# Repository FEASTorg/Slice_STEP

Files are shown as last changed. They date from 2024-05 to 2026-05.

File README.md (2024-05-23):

<div align="center">
  <!-- Title: -->
  <a href="https://github.com/uwo-fast">
    
  </a>
  <h2><a href="https://github.com/uwo-fast/Slice_STEP"> STEP Slice </a></h2>
  <!-- Labels: -->
  <!-- First row: -->
  <a href="https://github.com/uwo-fast/.github/blob/main/collaborating.md">
    
  </a>
  <a href="https://github.com/uwo-fast/.github/blob/main/contributing.md">
    
  </a>
  <a href="https://www.appropedia.org/Category:FAST_literature_reviews">
    
  </a>
  <a href="https://certification.oshwa.org/">
    
    <!-- img src="https://img.shields.io/badge/OSHWA-Certified-darkgreen?style=flat-square" height="20" alt="OSHWA" -->       <!-- img src="https://img.shields.io/badge/OSHWA-Pending-darkorange?style=flat-square" height="20" alt="OSHWA" -->
  </a>
  <a href="https://osf.io/">
    
  </a>
  <a href="https://doi.org">
    
  </a>
  <!-- Second row: -->
  <br>
  <a href="https://github.com/uwo-fast/Slice_STEP/blob/main/LICENSE">
    
  </a>
  <a href="https://github.com/uwo-fast/Slice_STEP">
    
  </a>
  <a href="https://github.com/uwo-fast/Slice_STEP/issues">
    
  </a>
  <a href="https://github.com/uwo-fast/Slice_STEP/network/members">
    
  </a>
  <a href="https://github.com/uwo-fast/Slice_STEP/stargazers">
    
  </a>
  <!-- Short description: -->
  <h3>Stepper Motor Driver Carrier Slice for BREAD.</h3>
</div>

## Introduction
[Provide a brief introduction to the project, including the motivation and goals. Explain the significance and context of the research.]

## Project Overview
[Describe the project in more detail. This section can be split into subsections if necessary.]

## Installation
[Provide instructions for installing any necessary software or hardware components.]

## Usage
[Explain how to use the project. Include examples and screenshots if applicable.]

### Basic Usage
[Provide basic usage instructions.]

### Advanced Usage
[Provide advanced usage instructions, including any optional features or configurations.]

## Documentation
[Link to the detailed documentation if available. Provide instructions on how to access and navigate the documentation.]

## Contributing
[Explain how others can contribute to the project. Include guidelines for submitting issues, pull requests, and any coding standards.]

### Code of Conduct
[Link to the project's code of conduct if available.]

## License
[State the license under which the project is distributed. Include a link to the full license text.]

## Acknowledgements
[Acknowledge any contributors, collaborators, funding sources, or organizations that supported the project.]

## Contact
[Provide contact information for the project maintainer(s) or lead researcher(s). Include an email address or a link to a contact form.]

---

<div align="center">
  <p>
    
    
  </p>
</div>

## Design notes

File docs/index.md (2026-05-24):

---
title: "Slice STEP Documentation"
description: "Overview and entry page for Slice STEP project documentation."
nav_exclude: true
---

Welcome to the Slice STEP project documentation.

## Board Renders

<figure style="display:inline-block; text-align:center; margin:10px;">
  Board Top
  <figcaption>Top</figcaption>
</figure>

<figure style="display:inline-block; text-align:center; margin:10px;">
  Board Bottom
  <figcaption>Bottom</figcaption>
</figure>

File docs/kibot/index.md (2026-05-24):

---
title: "KiBot Outputs"
description: "Index for KiBot-generated PCB artifacts."
layout: "page"
---

These are the docs & KiBot Outputs for Slice STEP

The following files were generated from the latest PCB build:

- [Schematic.pdf](./Schematic.pdf)
- [PCB.pdf](./PCB.pdf)
- [kibot.log](./kibot.log)
- [BREAD_Slice-bom.html](./BREAD_Slice-bom.html)
- [BREAD_Slice-ibom.html](./BREAD_Slice-ibom.html)

_Last updated automatically by KiBot via GitHub Actions._

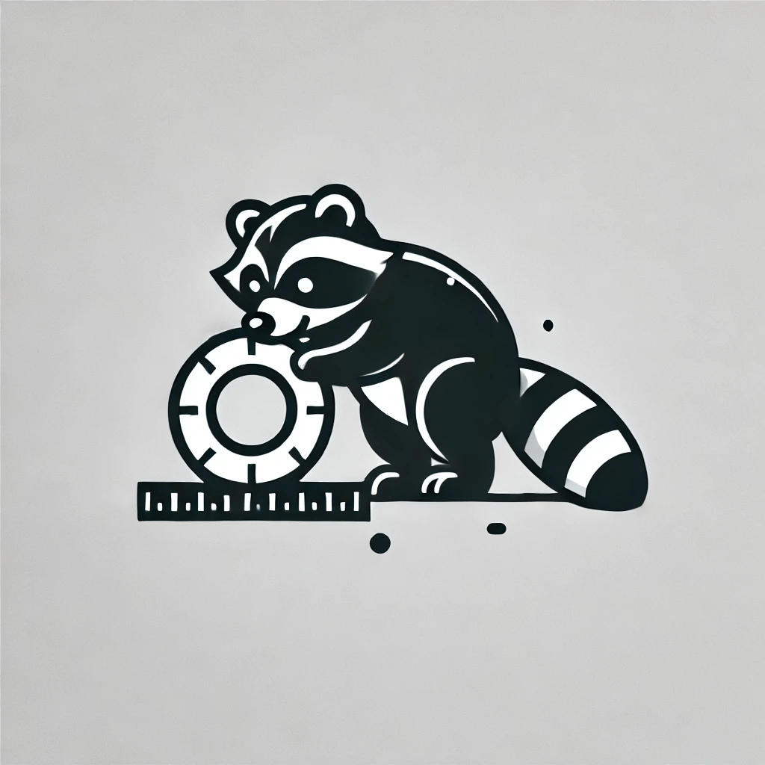
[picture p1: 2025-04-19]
hardware/stepping-raccoon.png

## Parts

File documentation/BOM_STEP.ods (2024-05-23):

Id | Designator | Package | Quantity | Designation | Supplier and ref
1 | J5 | PinSocket_1x03_P2.54mm_Vertical | 1 | Conn_01x03_Male | https://www.digikey.ca/en/products/detail/sullins-connector-solutions/PREC003SAAN-RC/2774851
2 | C3,C1,C2 | C_2312 | 3 | 10uF_t | https://www.digikey.ca/short/qfrbqfhd
3 | J6 | TerminalBlock_TE_282834-2_1x02_P2.54mm_Horizontal | 1 | Screw_Terminal_01x02 | https://www.digikey.ca/en/products/detail/on-shore-technology-inc/OSTVN02A150/1588862
4 | R4,R3,R2,R1 | R_1206_3216Metric_Pad1.30x1.75mm_HandSolder | 4 | 1k | https://www.digikey.ca/en/products/detail/stackpole-electronics-inc/RMCF1206FT1K00/1759616
5 | J4,J3 | TerminalBlock_TE_282834-8_1x08_P2.54mm_Horizontal | 2 | Screw_Terminal_01x08 | https://www.digikey.ca/en/products/detail/on-shore-technology-inc/OSTVN08A150/1588868
6 | J2 | TerminalBlock_TE_282834-4_1x04_P2.54mm_Horizontal | 1 | Screw_Terminal_01x04 | https://www.digikey.ca/short/tv7tzq1r
7 | A4,A3,A2,A1 | Pololu_Breakout-16_15.2x20.3mm | 4 | Pololu_Breakout_A4988 | https://www.pololu.com/product/1182
8 | G1 | Arduino_Nano | 1 | Arduino_Nano_v3.x | https://www.digikey.ca/en/products/detail/arduino/A000005/2638989
9 | J1 | PinSocket_1x10_P2.54mm_Horizontal | 1 | Conn_01x10_Female | https://www.digikey.ca/en/products/detail/sullins-connector-solutions/PPPC101LGBN-RC/775943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

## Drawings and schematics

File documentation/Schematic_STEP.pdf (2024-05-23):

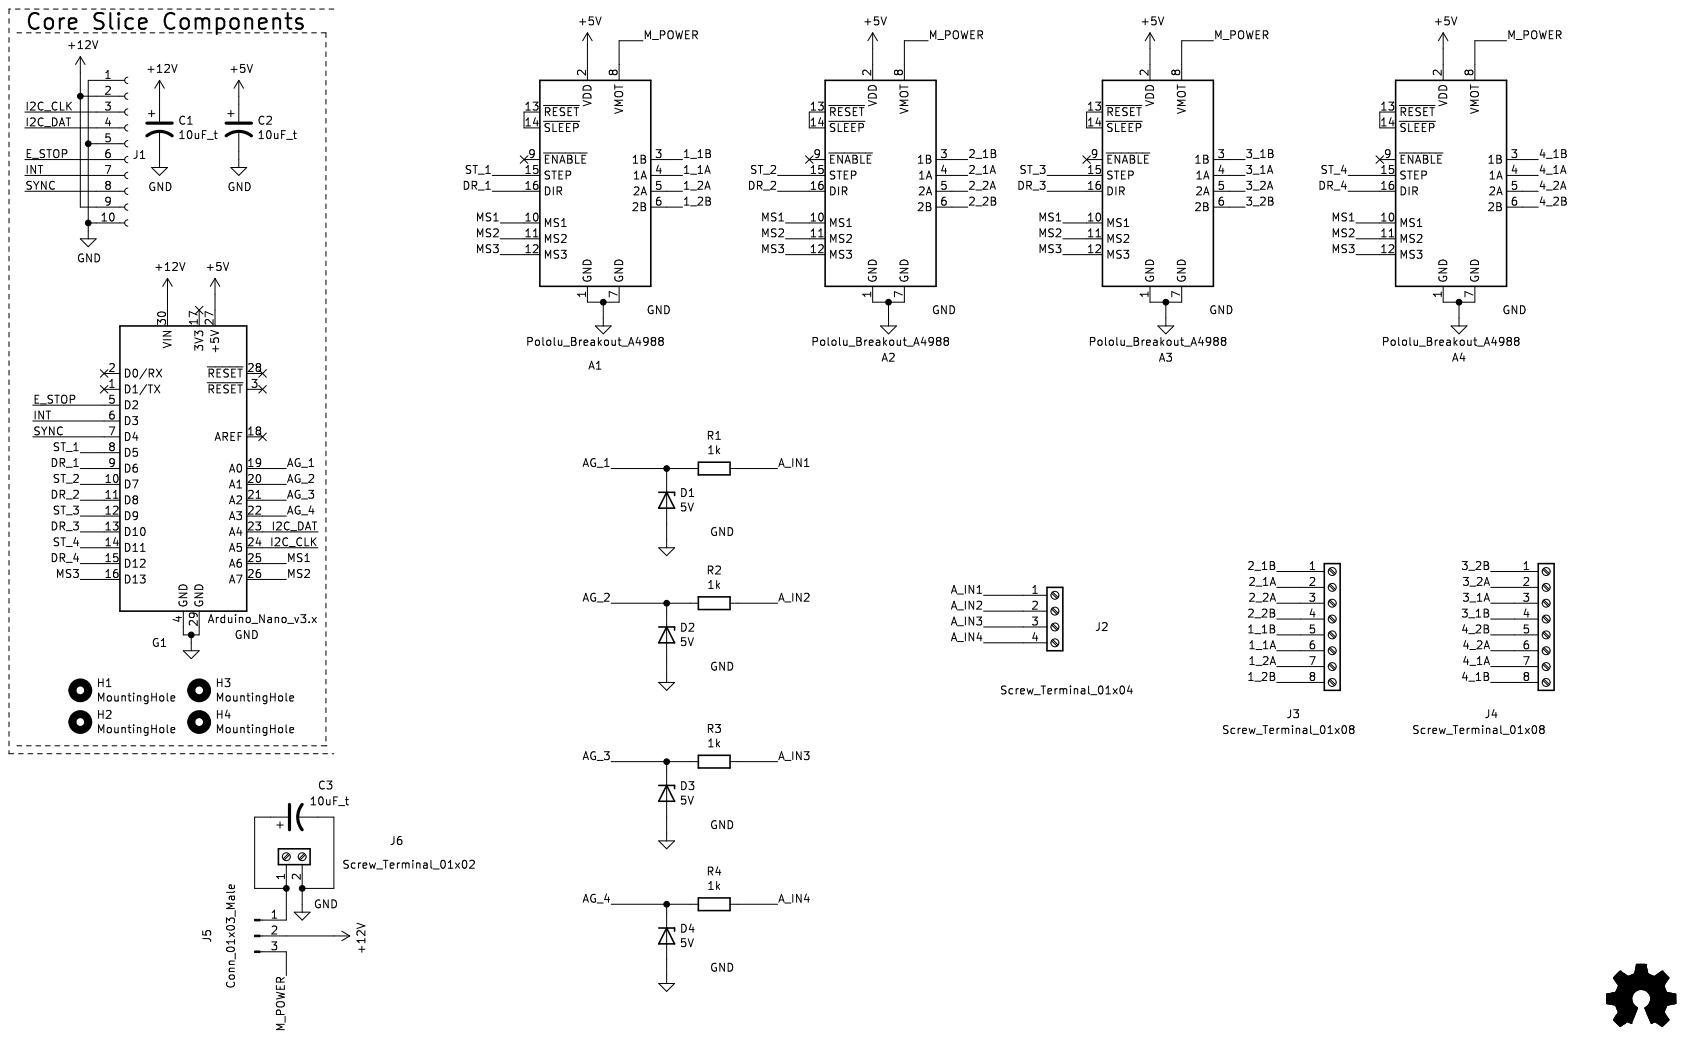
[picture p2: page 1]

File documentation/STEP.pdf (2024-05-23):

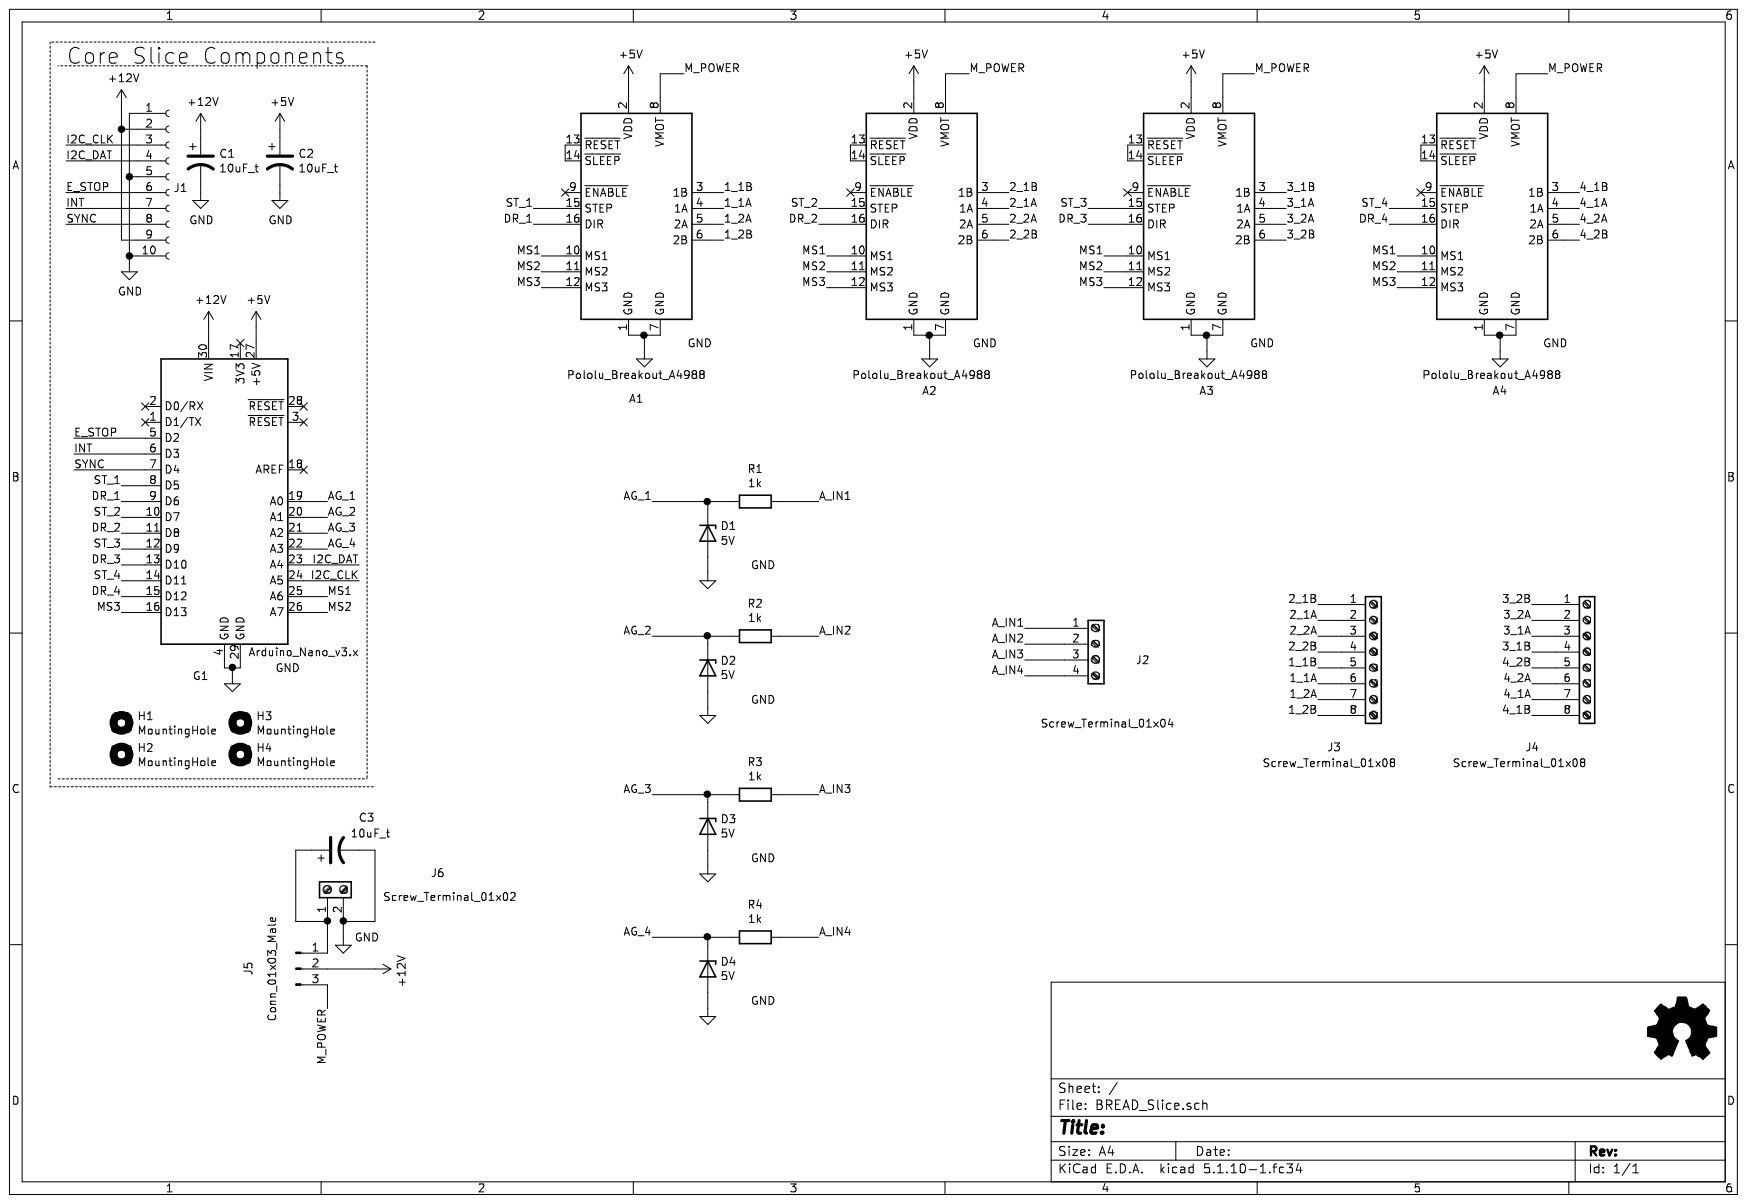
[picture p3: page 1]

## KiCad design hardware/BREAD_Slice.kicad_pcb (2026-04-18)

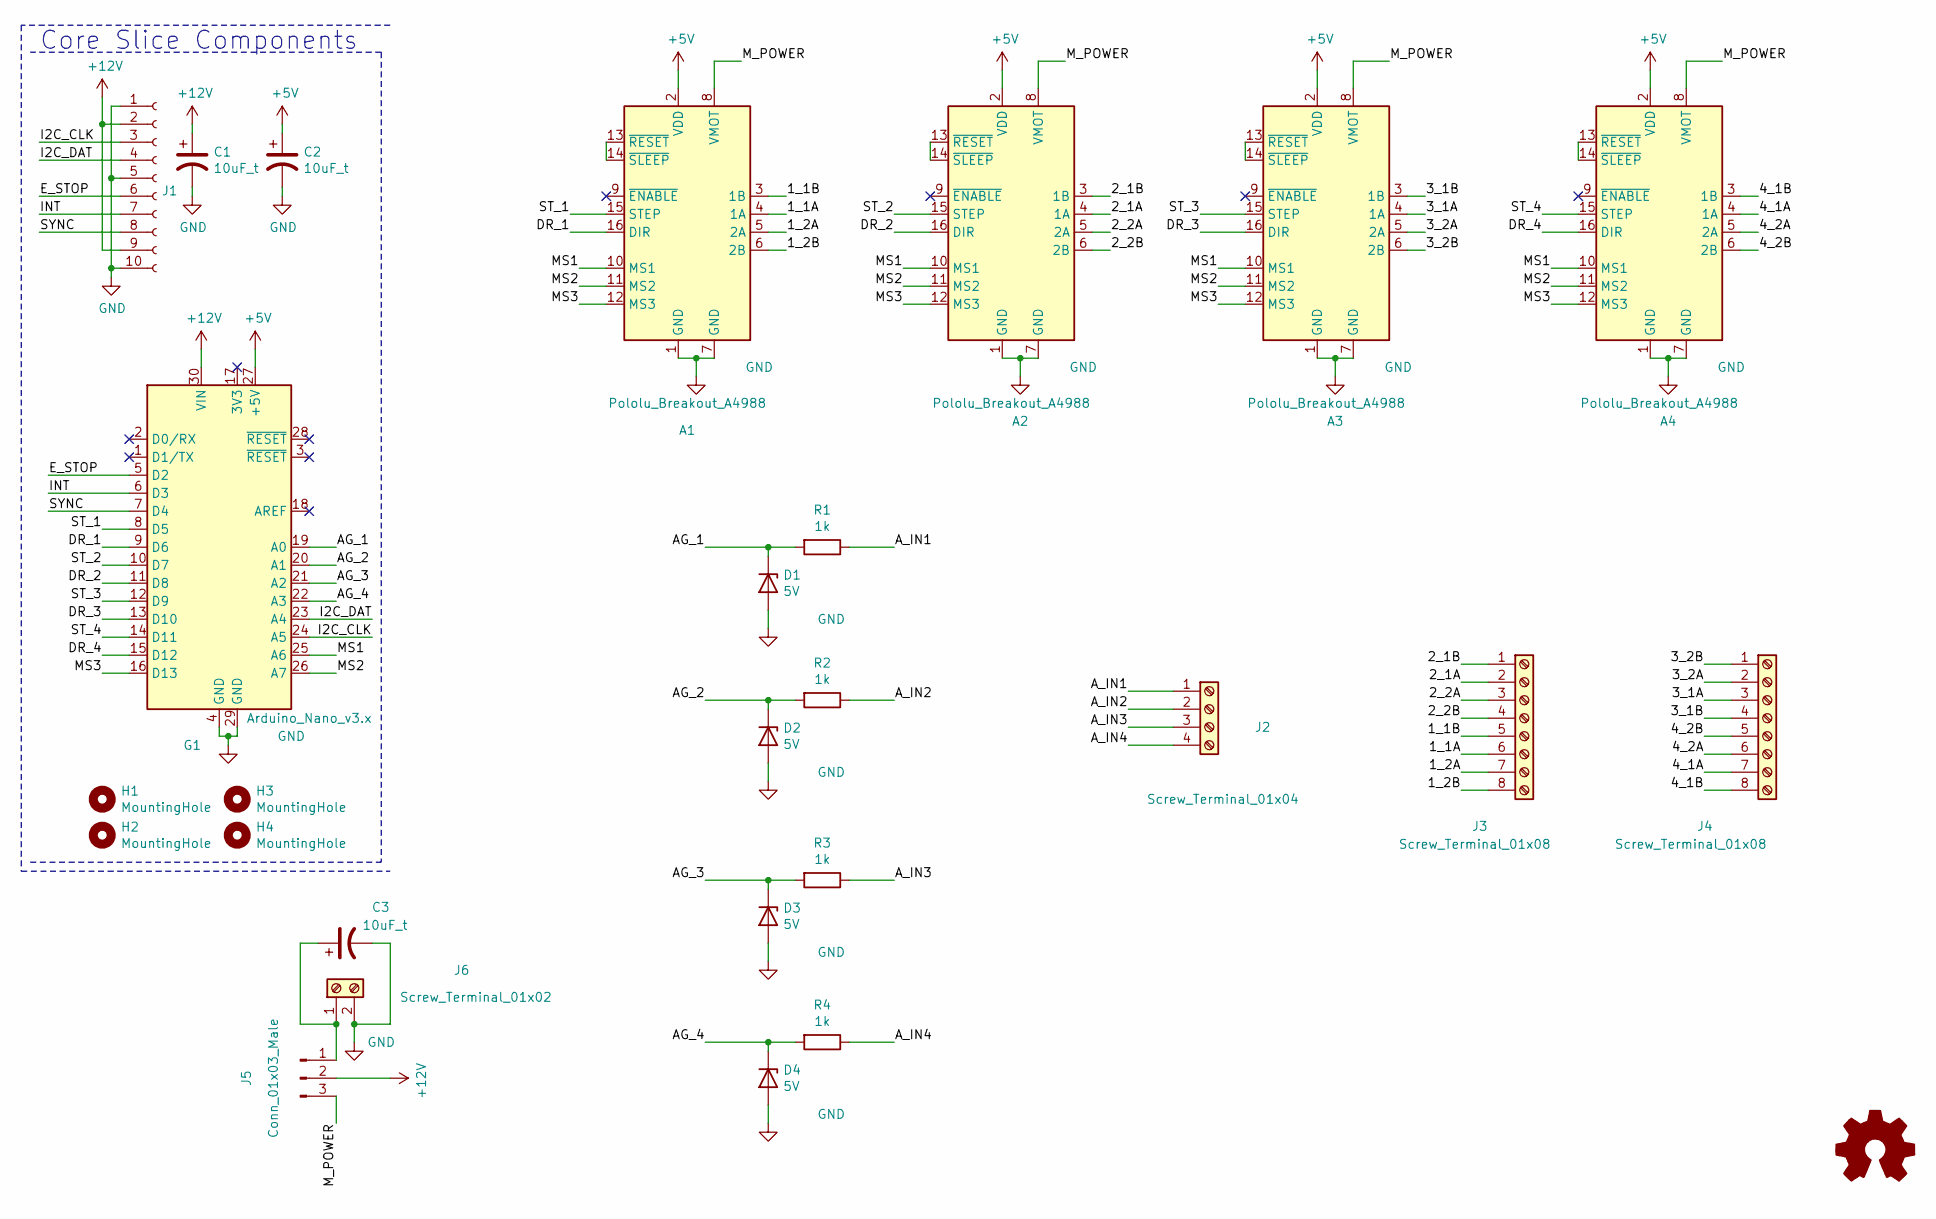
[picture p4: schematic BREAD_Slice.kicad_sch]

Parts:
A1, A2, A3, A4: Pololu_Breakout_A4988; Pololu_Breakout-16_15.2x20.3mm
C1, C2, C3: 10uF_t; C_2312; Part # T491C106K025AT
D1, D2, D3, D4: 5V; D_1206_3216Metric_Pad1.42x1.75mm_HandSolder
G1: Arduino_Nano_v3.x; Arduino_Nano
H1, H2, H3, H4: MountingHole; MountingHole_3.2mm_M3_DIN965_Pad
J1: Conn_01x10_Female; PinSocket_1x10_P2.54mm_Horizontal
J2: Screw_Terminal_01x04; TerminalBlock_TE_282834-4_1x04_P2.54mm_Horizontal
J3, J4: Screw_Terminal_01x08; TerminalBlock_TE_282834-8_1x08_P2.54mm_Horizontal
J5: Conn_01x03_Male; PinSocket_1x03_P2.54mm_Vertical
J6: Screw_Terminal_01x02; TerminalBlock_TE_282834-2_1x02_P2.54mm_Horizontal
Logo1: Logo_Open_Hardware_Small; OSHW-Symbol_6.7x6mm_SilkScreen
R1, R2, R3, R4: 1k; R_1206_3216Metric_Pad1.30x1.75mm_HandSolder

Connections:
+5V: A1.2 (VDD), A2.2 (VDD), A3.2 (VDD), A4.2 (VDD), C2.1, G1.27 (+5V)
+12V: C1.1, G1.30 (VIN), J1.2, J1.9, J5.2
/1_1A: A1.4 (1A), J3.6
/1_1B: A1.3 (1B), J3.5
/1_2A: A1.5 (2A), J3.7
/1_2B: A1.6 (2B), J3.8
/2_1A: A2.4 (1A), J3.2
/2_1B: A2.3 (1B), J3.1
/2_2A: A2.5 (2A), J3.3
/2_2B: A2.6 (2B), J3.4
/3_1A: A3.4 (1A), J4.3
/3_1B: A3.3 (1B), J4.4
/3_2A: A3.5 (2A), J4.2
/3_2B: A3.6 (2B), J4.1
/4_1A: A4.4 (1A), J4.7
/4_1B: A4.3 (1B), J4.8
/4_2A: A4.5 (2A), J4.6
/4_2B: A4.6 (2B), J4.5
/AG_1: D1.1 (K), G1.19 (A0), R1.2
/AG_2: D2.1 (K), G1.20 (A1), R2.2
/AG_3: D3.1 (K), G1.21 (A2), R3.2
/AG_4: D4.1 (K), G1.22 (A3), R4.2
/A_IN1: J2.1, R1.1
/A_IN2: J2.2, R2.1
/A_IN3: J2.3, R3.1
/A_IN4: J2.4, R4.1
/DR_1: A1.16 (DIR), G1.9 (D6)
/DR_2: A2.16 (DIR), G1.11 (D8)
/DR_3: A3.16 (DIR), G1.13 (D10)
/DR_4: A4.16 (DIR), G1.15 (D12)
/E_STOP: G1.5 (D2), J1.6
/I2C_CLK: G1.24 (A5), J1.3
/I2C_DAT: G1.23 (A4), J1.4
/INT: G1.6 (D3), J1.7
/MS1: A1.10 (MS1), A2.10 (MS1), A3.10 (MS1), A4.10 (MS1), G1.25 (A6)
/MS2: A1.11 (MS2), A2.11 (MS2), A3.11 (MS2), A4.11 (MS2), G1.26 (A7)
/MS3: A1.12 (MS3), A2.12 (MS3), A3.12 (MS3), A4.12 (MS3), G1.16 (D13)
/M_POWER: A1.8 (VMOT), A2.8 (VMOT), A3.8 (VMOT), A4.8 (VMOT), J5.3
/ST_1: A1.15 (STEP), G1.8 (D5)
/ST_2: A2.15 (STEP), G1.10 (D7)
/ST_3: A3.15 (STEP), G1.12 (D9)
/ST_4: A4.15 (STEP), G1.14 (D11)
/SYNC: G1.7 (D4), J1.8
GND: A1.1 (GND), A1.7 (GND), A2.1 (GND), A2.7 (GND), A3.1 (GND), A3.7 (GND), A4.1 (GND), A4.7 (GND), C1.2, C2.2, C3.2, D1.2 (A), D2.2 (A), D3.2 (A), D4.2 (A), G1.4 (GND), G1.29 (GND), J1.1, J1.5, J1.10, J6.2
unnamed: A1.13 (~RESET), A1.14 (~SLEEP)
unnamed: A2.13 (~RESET), A2.14 (~SLEEP)
unnamed: A3.13 (~RESET), A3.14 (~SLEEP)
unnamed: A4.13 (~RESET), A4.14 (~SLEEP)
unnamed: C3.1, J5.1, J6.1

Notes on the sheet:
Core Slice Components

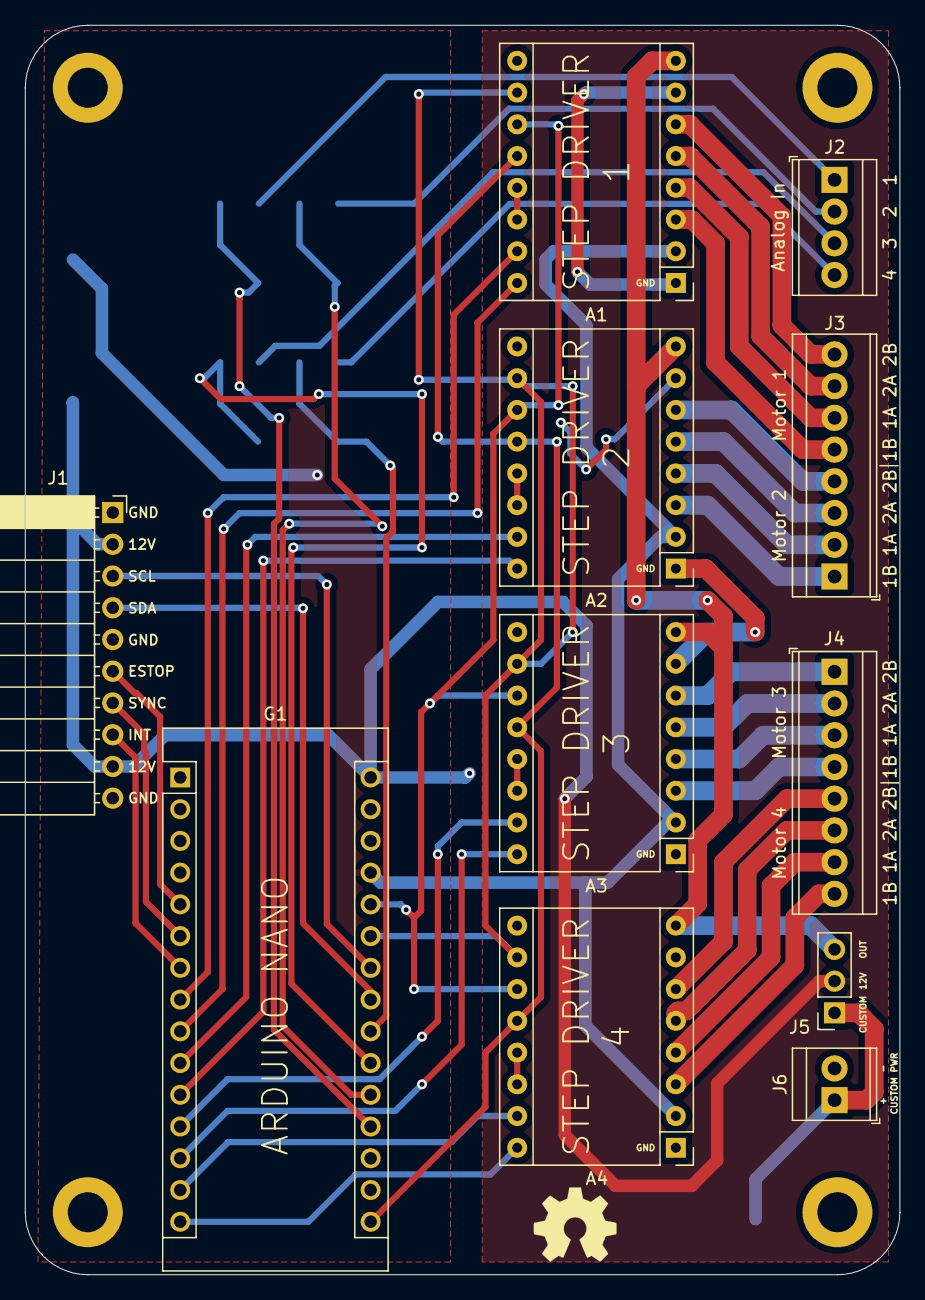
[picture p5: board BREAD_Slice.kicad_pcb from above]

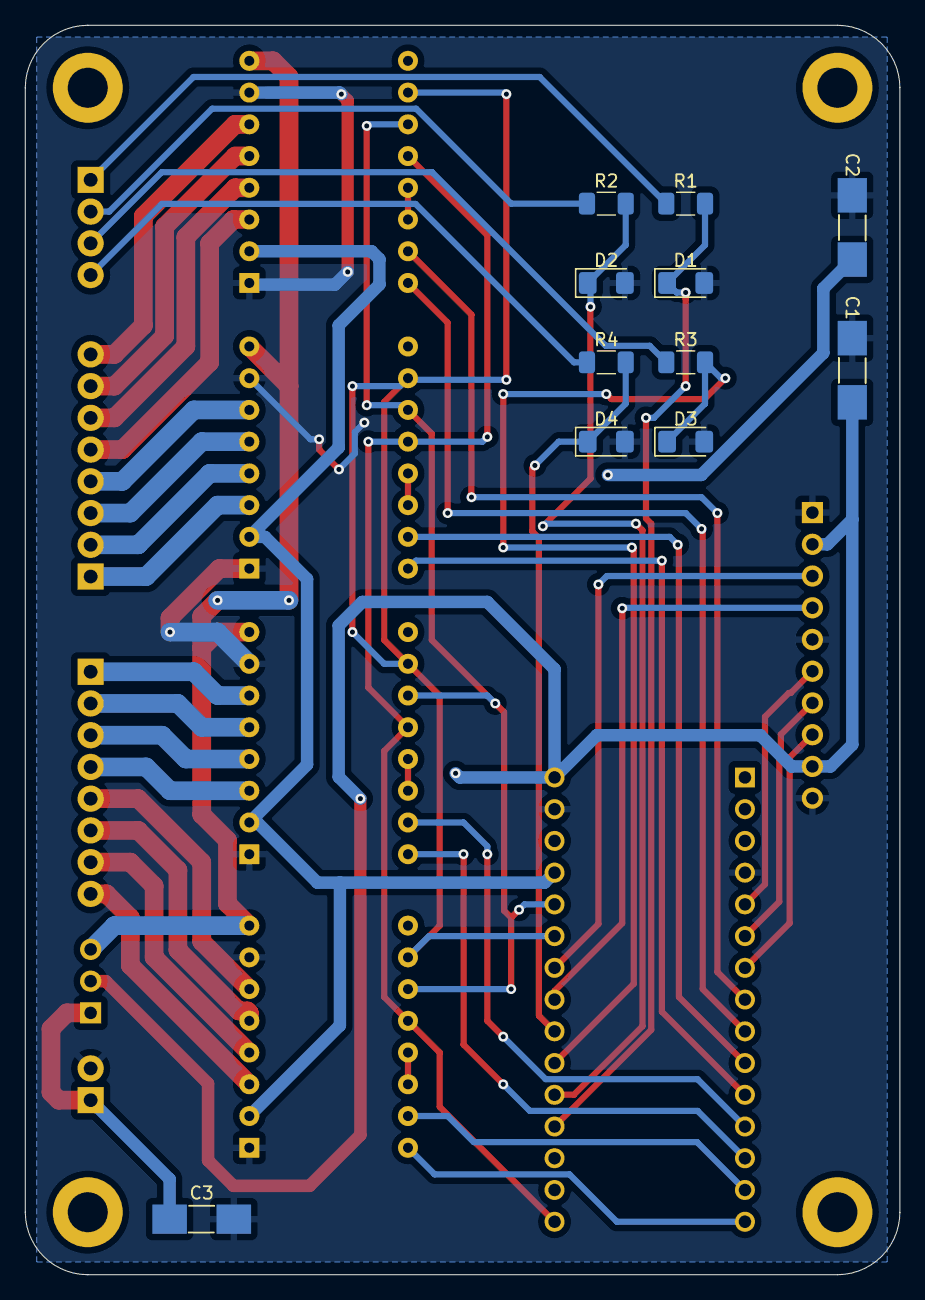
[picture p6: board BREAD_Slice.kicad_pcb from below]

Board: 2 copper layers, 70.0 x 100.0 mm, 27 parts (11 on the bottom side), 49 nets.

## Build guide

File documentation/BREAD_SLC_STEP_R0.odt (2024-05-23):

# Broadly Reconfigurable and Expandable Automation Device (BREAD) – Slice Datasheet: Stepper Motor Control Slice (SLC-STEP)

By: Nicholas Whisman (ngwhisma@mtu.edu) – Revision 0, on 18. May 2021

## Short Device Description

This device is designed to very finely control up to four stepper motors. The system has a feedback path in the form of 4 analog inputs. Finer control can be achieved by utilizing the microstep pin connections.

## Quick Information

Device at a Glance

Short title | Stepper Motor Control Slice
Part # | SLC-STEP
Repository Link | Link to OSF or other repository
Academic Paper DOI | DOI link to published paper
Device Cost | Monetary cost of the device
Assembly Difficulty | Difficult, Millable
Application Area | Controls, Robotics

Device Connections

J2 – Analog Input Paths

Pin # | Description | Rating
1 | Analog Input 1 | 5V
2 | Analog Input 2 | 5V
3 | Analog Input 3 | 5V
4 | Analog Input 4 | 5V

J3 – Output to Stepper

Pin # | Description | Rating
1 | Motor 2, Signal 1B | ±2A
2 | Motor 2, Signal 1A | ±2A
3 | Motor 2, Signal 2A | ±2A
4 | Motor 2, Signal 2B | ±2A
5 | Motor 1, Signal 1B | ±2A
6 | Motor 1, Signal 1A | ±2A
7 | Motor 1, Signal 2A | ±2A
8 | Motor 1, Signal 2B | ±2A

J4 – Output to Stepper

Pin # | Description | Rating
1 | Motor 3, Signal 2B | ±2A
2 | Motor 3, Signal 2A | ±2A
3 | Motor 3, Signal 1A | ±2A
4 | Motor 3, Signal 1B | ±2A
5 | Motor 4, Signal 2B | ±2A
6 | Motor 4, Signal 2A | ±2A
7 | Motor 4, Signal 1A | ±2A
8 | Motor 4, Signal 1B | ±2A

## Commands

Set Up (no significant returns)
Byte: Address | Bit: 1 | Float: Target Temp | Float: Ramp Rate (d/m)
Speed Select (no significant returns)
Byte: Address | Bit: 0 | Float: 0 | Float: 0
Step Select (no significant returns)
Analog Read (returns voltage on selected analog input line)

## Schematic

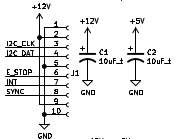
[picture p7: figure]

Figure 1: BREAD Connection Port and Power Capacitors

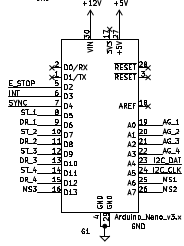
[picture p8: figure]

Figure 2: Arduino Nano

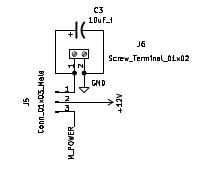
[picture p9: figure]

Figure 3: Custom Power Select

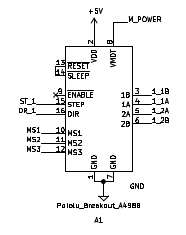
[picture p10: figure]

Figure 4: One of four breakout stepper motor drivers

Figure 5: One of four feedback voltage paths

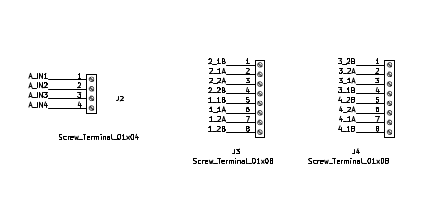
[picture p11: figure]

Figure 6: Signal Input Ports

## Bill of Materials

Designator | Description | Quantity | Cost / part | URL
J5 | 01x03 1/10” Pitch Male Connector Pins | 1 | 0.27 | https://www.digikey.com/short/jv0b95z0
C1-3 | 1206 Packaging 10 µF Capacitor | 3 | 0.64 | https://www.digikey.com/short/qfrbqfhd
J6 | 01x02 1/10” Pitch Terminal Block | 1 | 1.27 | https://www.digikey.com/short/0v8hf4h8
R1-4 | 1k 1206 Packaging Resistor | 4 | 0.10 | https://www.digikey.com/short/wp8502p7
J3-4 | 01x08 1/10” Pitch Terminal Block | 2 | 6.45 | https://www.digikey.com/short/mqn9fd88
J2 | 01x04 1/10” Pitch Terminal Block | 1 | 2.75 | https://www.digikey.com/short/tv7tzq1r
D1-4 | 5.1V Zener Diode | 4 | 0.22 | https://www.digikey.com/short/z0f0ztp2
A1-4 | Pololu A4988 Stepper Driver | 4 | 5.95 | https://www.pololu.com/category/156/a4988-stepper-motor-driver-carriers
G1 | Arduino Nano | 1 | 22.00 | https://www.digikey.com/en/products/detail/arduino/A000005/2638989
J1 | 01x10 Female Header Pins | 1 | 0.79 | https://www.digikey.com/short/23bfwwjh

## Construction & Fabrication

List any tools that are required and short guide on the order which parts should be soldered / assembled. Be sure to note any specialized methods and point out components that may easily be soldered in the incorrect orientation. Additionally include at least one picture of the assembled board (include both sides if there are components on both sides).

[Image of the assembled Circuit Board]

Fig #. Subtitle should go here.

## Configuration & Calibration

Include a list of default jumper and potentiometer positions:

Hardware Positions

- Turn P1 to be roughly 50%
- Turn P2 to be completely closed (turn clockwise until potentiometer clicks)
- Place a jumper to short out J3. Etc…

Detail any key parameters the end-user may want to adjust in the firmware, and if there are any special instructions before programming the Slice.

Tools Required For Calibration

- An oscilloscope with at least 15Mhz sampling
- A multimeter. Etc…

List all of the tools / instruments required for calibration. Provide a detailed & step by step guide on how to calibrate (or validate) each unique type of channel on the card. Include what variables in the firmware may need to be adjusted (and when). Attach a wiring diagram for each relevant calibration circuit.

[Image of the calibration circuit]

Fig #. Subtitle should go here.

## Usage & Constraints

List the relevant constraints for each type of channel on the card. These parameters may be quantities like max current, max voltage, frequency, sampling frequency, etc.

List an example wiring diagram of the slice in use, as well as some suggested applications

[Image of the example usage wiring diagram]

Fig #. Subtitle should go here.

## General Comments on Slice

This section is intended as a catch-all for any topics that are relevant to the Slice that don’t fit in any other category.

## Revision Notes

- Rev 0 – Initial document release (DATE HERE)

SLC-STEP Datasheet – Revision 0

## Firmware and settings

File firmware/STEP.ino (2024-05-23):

// Include the AccelStepper Library
#include <AccelStepper.h>
#include <Wire.h>
#include <SPI.h>

#define I2C_ADR 20 //Set this however you want

typedef union //Define a float that can be broken up and sent via I2C
{
 float number;
 uint8_t bytes[4];
} FLOATUNION_t;

// bunches of these
FLOATUNION_t RX_P1;
FLOATUNION_t RX_P2;
FLOATUNION_t RX_P3;
FLOATUNION_t RX_P4;

// Define pin connections
const int dirPin1 = 6;
const int stepPin1 = 5;
const int dirPin2 = 8;
const int stepPin2 = 7;
const int dirPin3 = 10;
const int stepPin3 = 9;
const int dirPin4 = 12;
const int stepPin4 = 11;

// Variables for command parameters
int inputSteps1 = 0;
int inputSteps2 = 0;
int inputSteps3 = 0;
int inputSteps4 = 0;

int motornum, mtrMaxSpeed, Accel, mtrSpeed;
int pos1, pos2, pos3, pos4;

int F1;
int F2;
int F3;
int F4;

int F1_R=1;
int F2_R=1;
int F3_R=1;
int F4_R=1;

int Command;
int arg1;
int arg2;
int arg3, arg4, arg5;

byte motorMask; // which motors to use. bits 4-7 unused, bits 3-0 are motors 1-4 respectively for readability.
byte mode; //only valid inputs for now are 1, 2, 3. 


// Define motor interface type
#define motorInterfaceType 1

// Creates an instance
AccelStepper CH1(motorInterfaceType, stepPin1, dirPin1);
AccelStepper CH2(motorInterfaceType, stepPin2, dirPin2);
AccelStepper CH3(motorInterfaceType, stepPin3, dirPin3);
AccelStepper CH4(motorInterfaceType, stepPin4, dirPin4);

String inputString = "";         // a String to hold incoming data
boolean stringComplete = false;  // whether the string is complete

void setup() {

  Wire.begin(I2C_ADR);            // join i2c bus with address #8
  Wire.onReceive(receiveEvent); // register event
  Wire.onRequest(requestEvent);   // register event

  inputString.reserve(50);

  Serial.begin(115200);

  while (!Serial) delay(1); // wait for Serial on Leonardo/Zero, etc
  delay(500);

  motorMask = 15; //all on by default (15 is the max.)

  config(1, 1000, 50, 200); //put some default parameters here
  config(2, 1000, 50, 200); //put some default parameters here
  config(3, 1000, 50, 200); //put some default parameters here
  config(4, 1000, 50, 200); //put some default parameters here
 
  setStep(0,0,0);
}

void loop() {

  // rerun config constantly in case values change
  config(motornum, mtrMaxSpeed, Accel, mtrSpeed);
  //getFeedback();

  // check to make sure no mode overlap-- stop if yes
  switch(mode){
    case 1:
      //do a mode
      DCMode(motorMask);
      break;
    case 2:
      //do another
      ServoMode(motorMask, pos1, pos2, pos3, pos4); //make configurable
      break;
    case 3:
      //final one
      StepMode(motorMask, inputSteps1, inputSteps2, inputSteps3, inputSteps4); //make configurable
      break;
    default:
      //do nothing
      Serial.println("Please select only one mode");
      break;
  }

  if (stringComplete) {
    // clear the string:
    inputString = "";
    stringComplete = false;
  }

}

void config(int channel, int maxspeed, int acc, int setspeed){
  
  switch(channel){
    case 1:
      CH1.setMaxSpeed(maxspeed); //1000
      CH1.setAcceleration(acc); //50
      CH1.setSpeed(setspeed); //100
      break;

    case 2:
      CH2.setMaxSpeed(maxspeed); //1000
      CH2.setAcceleration(acc); //50
      CH2.setSpeed(setspeed); //100
      break;

    case 3:
      CH3.setMaxSpeed(maxspeed); //1000
      CH3.setAcceleration(acc); //50
      CH3.setSpeed(setspeed); //100
      break;

    case 4:
      CH4.setMaxSpeed(maxspeed); //1000
      CH4.setAcceleration(acc); //50
      CH4.setSpeed(setspeed); //100
      break;
  }
}

void DCMode(byte mask){
  
  if(bitRead(mask, 3)){
    CH1.runSpeed();
  }
  if(bitRead(mask, 2)){
    CH2.runSpeed();
  }
  if(bitRead(mask, 1)){
    CH3.runSpeed();
  }
  if(bitRead(mask, 0)){
    CH4.runSpeed();
  }
  
}

void ServoMode(byte mask, int loc1, int loc2, int loc3, int loc4){

  //might need additional control stuff
  
  CH1.moveTo(loc1);
  CH2.moveTo(loc2);
  CH3.moveTo(loc3);
  CH4.moveTo(loc4);
  
  // Move the motor one step
  if(bitRead(mask, 3)){
    CH1.run();
  }
  if(bitRead(mask, 2)){
    CH2.run();
  }
  if(bitRead(mask, 1)){
    CH3.run();
  }
  if(bitRead(mask, 0)){
    CH4.run();
  }
  
}

void StepMode(byte useMask, int steps1, int steps2, int steps3, int steps4){

  int maxSteps = steps1;
  int steps[4] = {steps1, steps2, steps3, steps4};

  //determine the max amount of steps for loop length
  for(int j=0; j<4; j++){
    if(maxSteps<steps[j]){
      maxSteps = steps[j];
    }
  }

  CH1.moveTo(steps1);
  CH2.moveTo(steps2);
  CH3.moveTo(steps3);
  CH4.moveTo(steps4);

  
  //loop through max steps, only step when activated or below required steps
  for(int i=0; i<maxSteps; i++){
    if(bitRead(useMask, 3) && (i<steps1)){
      CH1.run();
    }
    if(bitRead(useMask, 2) && (i<steps2)){
      CH2.run();
    }
    if(bitRead(useMask, 1) && (i<steps3)){
      CH3.run();
    }
    if(bitRead(useMask, 0) && (i<steps4)){
      CH4.run();
    }
    Serial.print("l o o p ");
    Serial.println(i);
    delay(10);
  }

  //set steps to zero so it needs to be manually reset?
  inputSteps1 = 0;
  inputSteps2 = 0;
  inputSteps3 = 0;
  inputSteps4 = 0;
}

//Function to go grab feedback paths
void getFeedback(){
  
  F1 = analogRead(A0);
  F2 = analogRead(A1);
  F3 = analogRead(A2);
  F4 = analogRead(A3);

  Serial.print(F1); 
  Serial.print(", ");
  Serial.print(F2); 
  Serial.print(", ");
  Serial.print(F3);
  Serial.print(", ");
  Serial.println(F4);
  
}

void setStep(int i, int j, int k){
  // i, j, k == MS1, MS2, MS3
  digitalWrite(13, k);
  digitalWrite(A6, i);
  digitalWrite(A7, j);
}

void home(int axis, int path){
  
}

void receiveEvent(int howMany) {
  RX_P1.number = 0; RX_P2.number = 0; RX_P3.number = 0; RX_P4.number = 0;
  int ByteCount = 0;
  while (1 <= Wire.available()) { // loop through all but the last
    if (ByteCount == 0)
    {
      RX_P1.bytes[0] = Wire.read(); // receive a byte as character
    }
    else if (ByteCount == 1)
    {
      RX_P2.bytes[0] = Wire.read(); // receive a byte as character
    }
    else if (ByteCount == 2)
    {
      RX_P3.bytes[0] = Wire.read(); // receive a byte as character
    }
    else if (ByteCount == 3)
    {
      RX_P4.bytes[ByteCount] = Wire.read(); // receive a byte as character
    }
    ByteCount++;
  }
  stringComplete = true;

}

void requestEvent() {

  //Send parameters if set to be requested
  if(F1_R){
    for (int i = 0; i <=3; i++)
    {
      Wire.write(RX_P1.bytes[i]);
    }
  }
  if(F2_R){
    for (int i = 0; i <=3; i++)
    {
      Wire.write(RX_P2.bytes[i]);
    }
  }
  if(F3_R){
    for (int i = 0; i <=3; i++)
    {
      Wire.write(RX_P3.bytes[i]);
    }
  }
  if(F4_R){
    for (int i = 0; i <=3; i++)
    {
      Wire.write(RX_P4.bytes[i]);
    }
  }
}

void serialEvent() {
  while (Serial.available()) {
    // get the new byte:
    char inChar = (char)Serial.read();
    // add it to the inputString:
    inputString += inChar;
    // if the incoming character is a newline, set a flag so the main loop can
    // do something about it:
    if (inChar == '\n') {
      stringComplete = true;


      int result = sscanf(inputString.c_str(), "%d,%d,%d,%d,%d,%d", &Command, &arg1, &arg2, &arg3, &arg4, &arg5);

      Serial.print(Command);
      Serial.print(", ");
      Serial.print(arg1);
      Serial.print(", ");
      Serial.print(arg2);
      Serial.print(", ");
      Serial.print(arg3);
      Serial.print(", ");
      Serial.print(arg4);
      Serial.print(", ");
      Serial.println(arg5);

      switch(Command){

        //disperse gathered variables according to command issued
        case 0: //set-up command
          motornum = arg1;
          mtrMaxSpeed = arg2;
          Accel = arg3;
          mtrSpeed = arg4;
          break;
          
        case 1: //DC Mode command
          mode = Command;
          motorMask = arg1;
          break;

        case 2: //Servo Mode command
          mode = Command;
          motorMask = arg1;
          pos1 = arg2;
          pos2 = arg3;
          pos3 = arg4;
          pos4 = arg5;
          break;

        case 3: //Single step command
          mode = Command;
          motorMask = arg1;
          inputSteps1 = arg2;
          inputSteps2 = arg3;
          inputSteps3 = arg4;
          inputSteps4 = arg5;
          break;

        default:
          mode = Command;
          Serial.println("oopsie poopsie, that's not a command, silly");
          
      }
    }
  }
}

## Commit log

2025-04-19 minor tweaks
    [BREAD_Slice.kicad_pcb]
2026-04-18 chore: revisions to step board
    [BREAD_Slice.kicad_pcb, BREAD_Slice.kicad_sch]
